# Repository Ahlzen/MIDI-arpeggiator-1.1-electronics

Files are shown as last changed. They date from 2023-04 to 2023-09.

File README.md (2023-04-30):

# MIDI-arpeggiator-1.1-electronics
Schematics and PCB design for MIDI Arpeggiator v1.1

For KiCad 7

Firmware at
https://github.com/Ahlzen/MIDI-arpeggiator-1.1-firmware

Case and panel at
https://github.com/Ahlzen/MIDI-arpeggiator-1.1-case

### 3rd Party Libraries used

Raspberry Pi Pico symbols, footprints and 3D models from
https://github.com/ncarandini/KiCad-RP-Pico
(CC-BY-SA 4.0)

Female DIN (MIDI) connector symbol and footprint from
https://github.com/nebs/eurocad

## Images and Resources

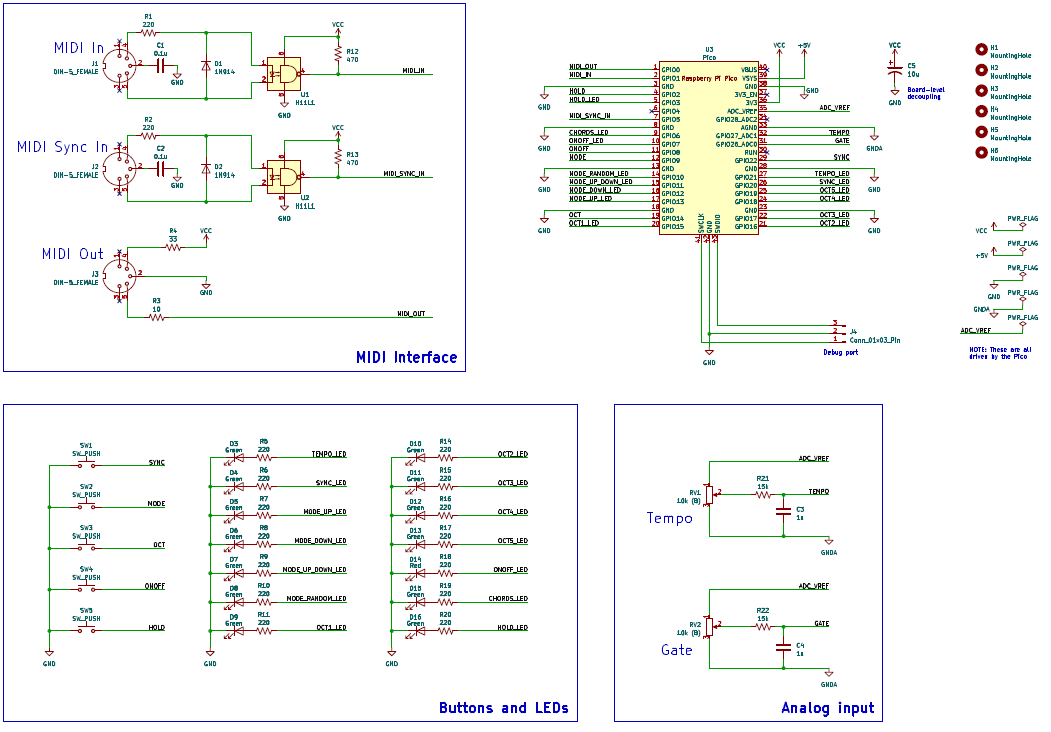
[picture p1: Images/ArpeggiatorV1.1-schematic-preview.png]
Schematic


[PDF Schematic](Images/ArpeggiatorV1.1.pdf)

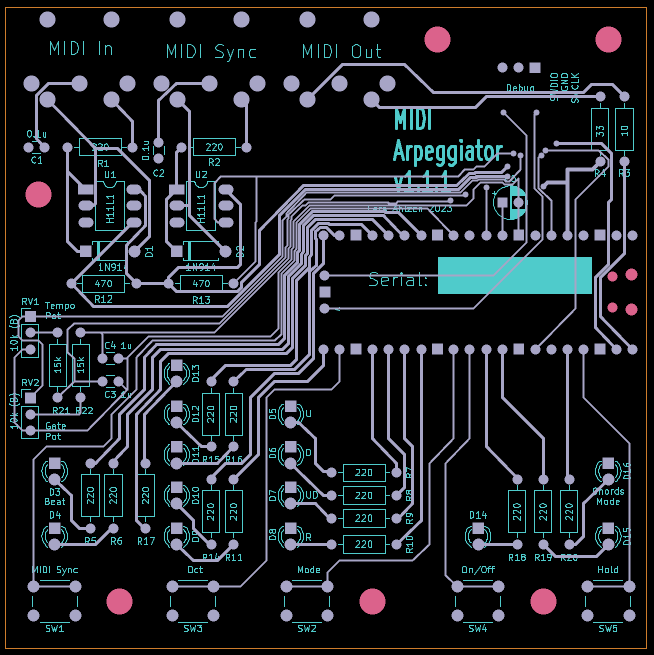
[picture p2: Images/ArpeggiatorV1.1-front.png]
PCB Front

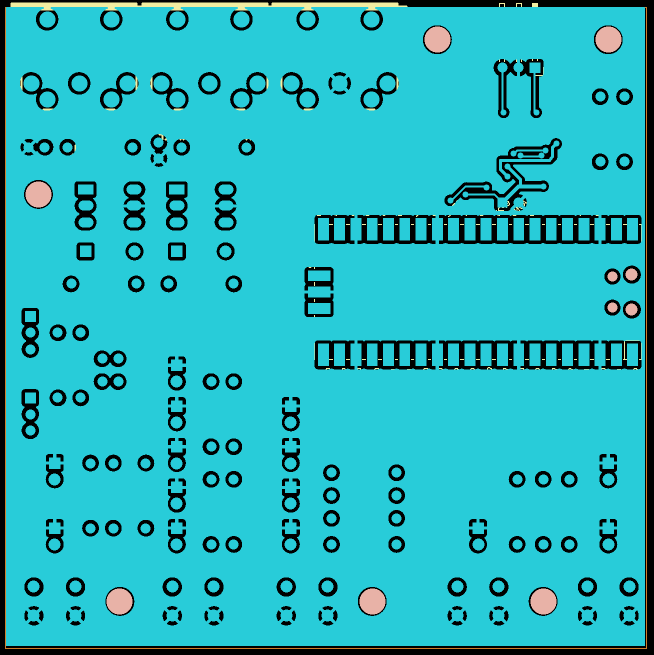
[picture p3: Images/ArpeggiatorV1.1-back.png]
PCB Back

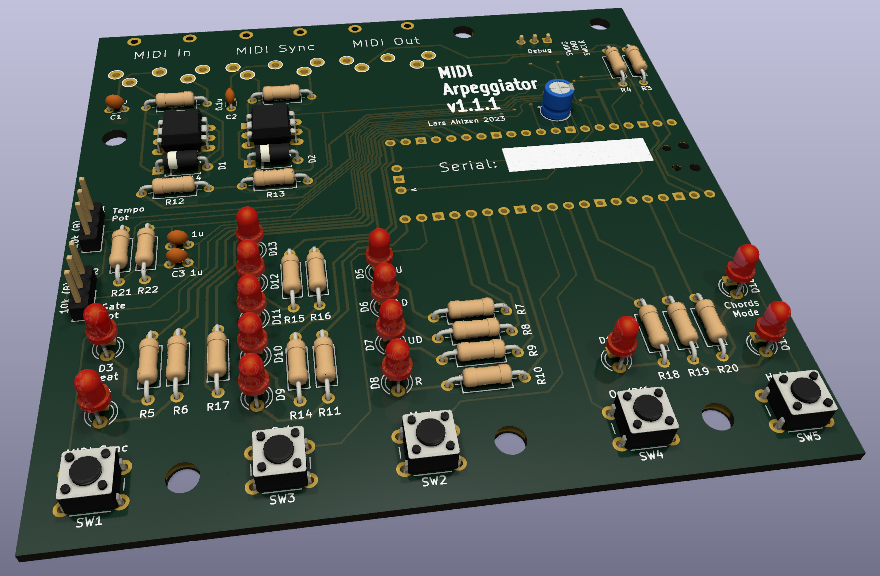
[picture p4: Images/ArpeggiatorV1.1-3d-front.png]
PCB Front (3D view)

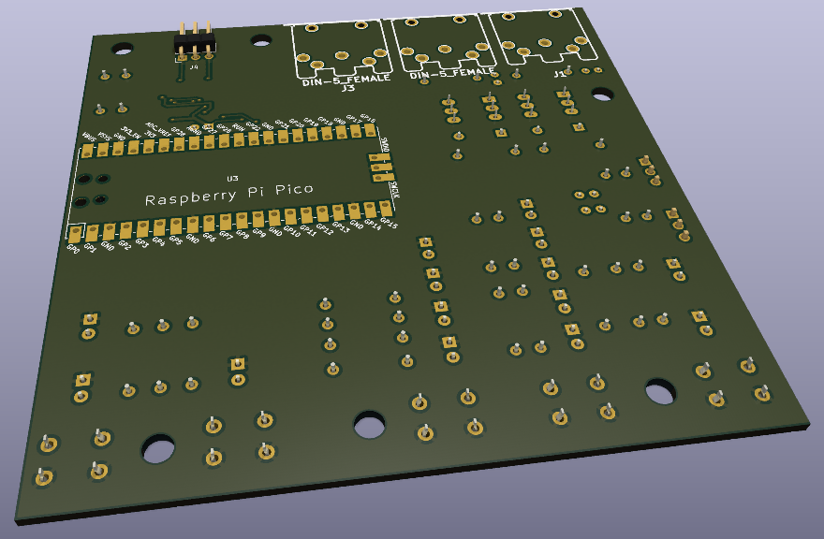
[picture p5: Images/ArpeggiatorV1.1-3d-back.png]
PCB Back (3D view)


## TODO

* Pull in KiCAD-RP-Pico and Eurocad libraries as submodules. [Done]
* Ensure all components values on schematic + PCB silkscreen [Done]
* Include proper BOM and build notes
* Add photos of assembled PCB

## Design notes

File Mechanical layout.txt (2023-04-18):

PCB Mechanical Layout
=====================
Notes on locations for panel elements (buttons, LEDs, connectors etc.)

All measurements in mm

Origin at top left
[0,0]->[100,0]
|
V
[0,100]

Buttons
-------
SW_SYNC   7.62, 92.71
SW_OCT   29.21, 92.71
SW_MODE  46.99, 92.71
SW_ONOFF 73.66, 92.71
SW_HOLD  93.98, 92.71

LEDs
----
Tempo:  7.62, 72.39
Sync:   7.62, 82.55
Oct1:   26.67, 82.55
Oct2:   26.67, 76.20
Oct3:   26.67, 69.85
Oct4:   26.67, 63.50
Oct5:   26.67, 57.15
ModeR:  44.45, 82.55
ModeUD: 44.45, 76.20
ModeD:  44.45, 69.85
ModeU:  44.45, 63.50
OnOff:  73.66, 82.55
Hold:   93.98, 82.55
Chords: 93.98, 72.39

Holes
-----
Top row:
5.08, 29.21
67.31, 5.08
93.98, 5.08
Bottom row:
17.78, 92.71
57.15, 92.71
83.82, 92.71

Back edge cutouts (below PCB)
----------------------------
MIDI ports: 0mm - 63mm  TODO: height
Debug port: 74mm - 86mm  TODO: height

Right edge cutouts (below PCB)
------------------------------
MicroUSB (power): 40mm - 49mm  TODO: height

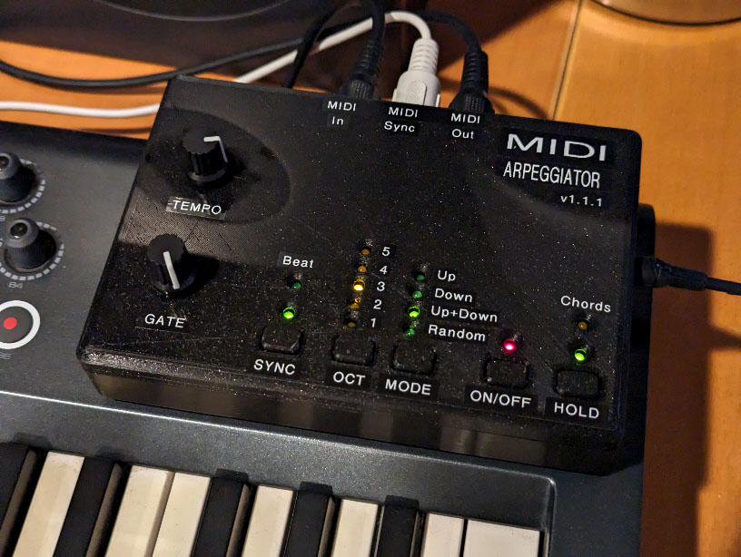
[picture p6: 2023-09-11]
Images/ArpeggiatorV1.1.1-photo.jpg

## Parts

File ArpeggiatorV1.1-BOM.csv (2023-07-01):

Reference | Value | Footprint | Qty
C1, C2 | 0.1u | Capacitor_THT:C_Disc_D3.0mm_W1.6mm_P2.50mm | 2
C3, C4 | 1u | Capacitor_THT:C_Disc_D3.0mm_W1.6mm_P2.50mm | 2
C5 | 10u | Capacitor_THT:CP_Radial_D5.0mm_P2.50mm | 1
D1, D2 | 1N914 | Diode_THT:D_A-405_P7.62mm_Horizontal | 2
D3-D13, D15, D16 | Green | LED_THT:LED_D3.0mm | 13
D14 | Red | LED_THT:LED_D3.0mm | 1
H1-H6 | MountingHole | MountingHole:MountingHole_4mm | 6
J1-J3 | DIN-5_FEMALE | Eurocad:MIDI_DIN5 | 3
J4 | Conn_01x03_Pin | Connector_PinHeader_2.54mm:PinHeader_1x03_P2.54mm_Horizontal | 1
R1, R2, R5-R11, R14-R20 | 220 | Resistor_THT:R_Axial_DIN0207_L6.3mm_D2.5mm_P10.16mm_Horizontal | 16
R3 | 10 | Resistor_THT:R_Axial_DIN0207_L6.3mm_D2.5mm_P10.16mm_Horizontal | 1
R4 | 33 | Resistor_THT:R_Axial_DIN0207_L6.3mm_D2.5mm_P10.16mm_Horizontal | 1
R12, R13 | 470 | Resistor_THT:R_Axial_DIN0207_L6.3mm_D2.5mm_P10.16mm_Horizontal | 2
R21, R22 | 15k | Resistor_THT:R_Axial_DIN0207_L6.3mm_D2.5mm_P10.16mm_Horizontal | 2
RV1, RV2 | 10k (B) | Connector_PinHeader_2.54mm:PinHeader_1x03_P2.54mm_Vertical | 2
SW1-SW5 | SW_PUSH | Button_Switch_THT:SW_PUSH_6mm | 5
U1, U2 | H11L1 | Package_DIP:DIP-6_W7.62mm_LongPads | 2
U3 | Pico | MCU_RaspberryPi_and_Boards:RPi_Pico_SMD_TH | 1

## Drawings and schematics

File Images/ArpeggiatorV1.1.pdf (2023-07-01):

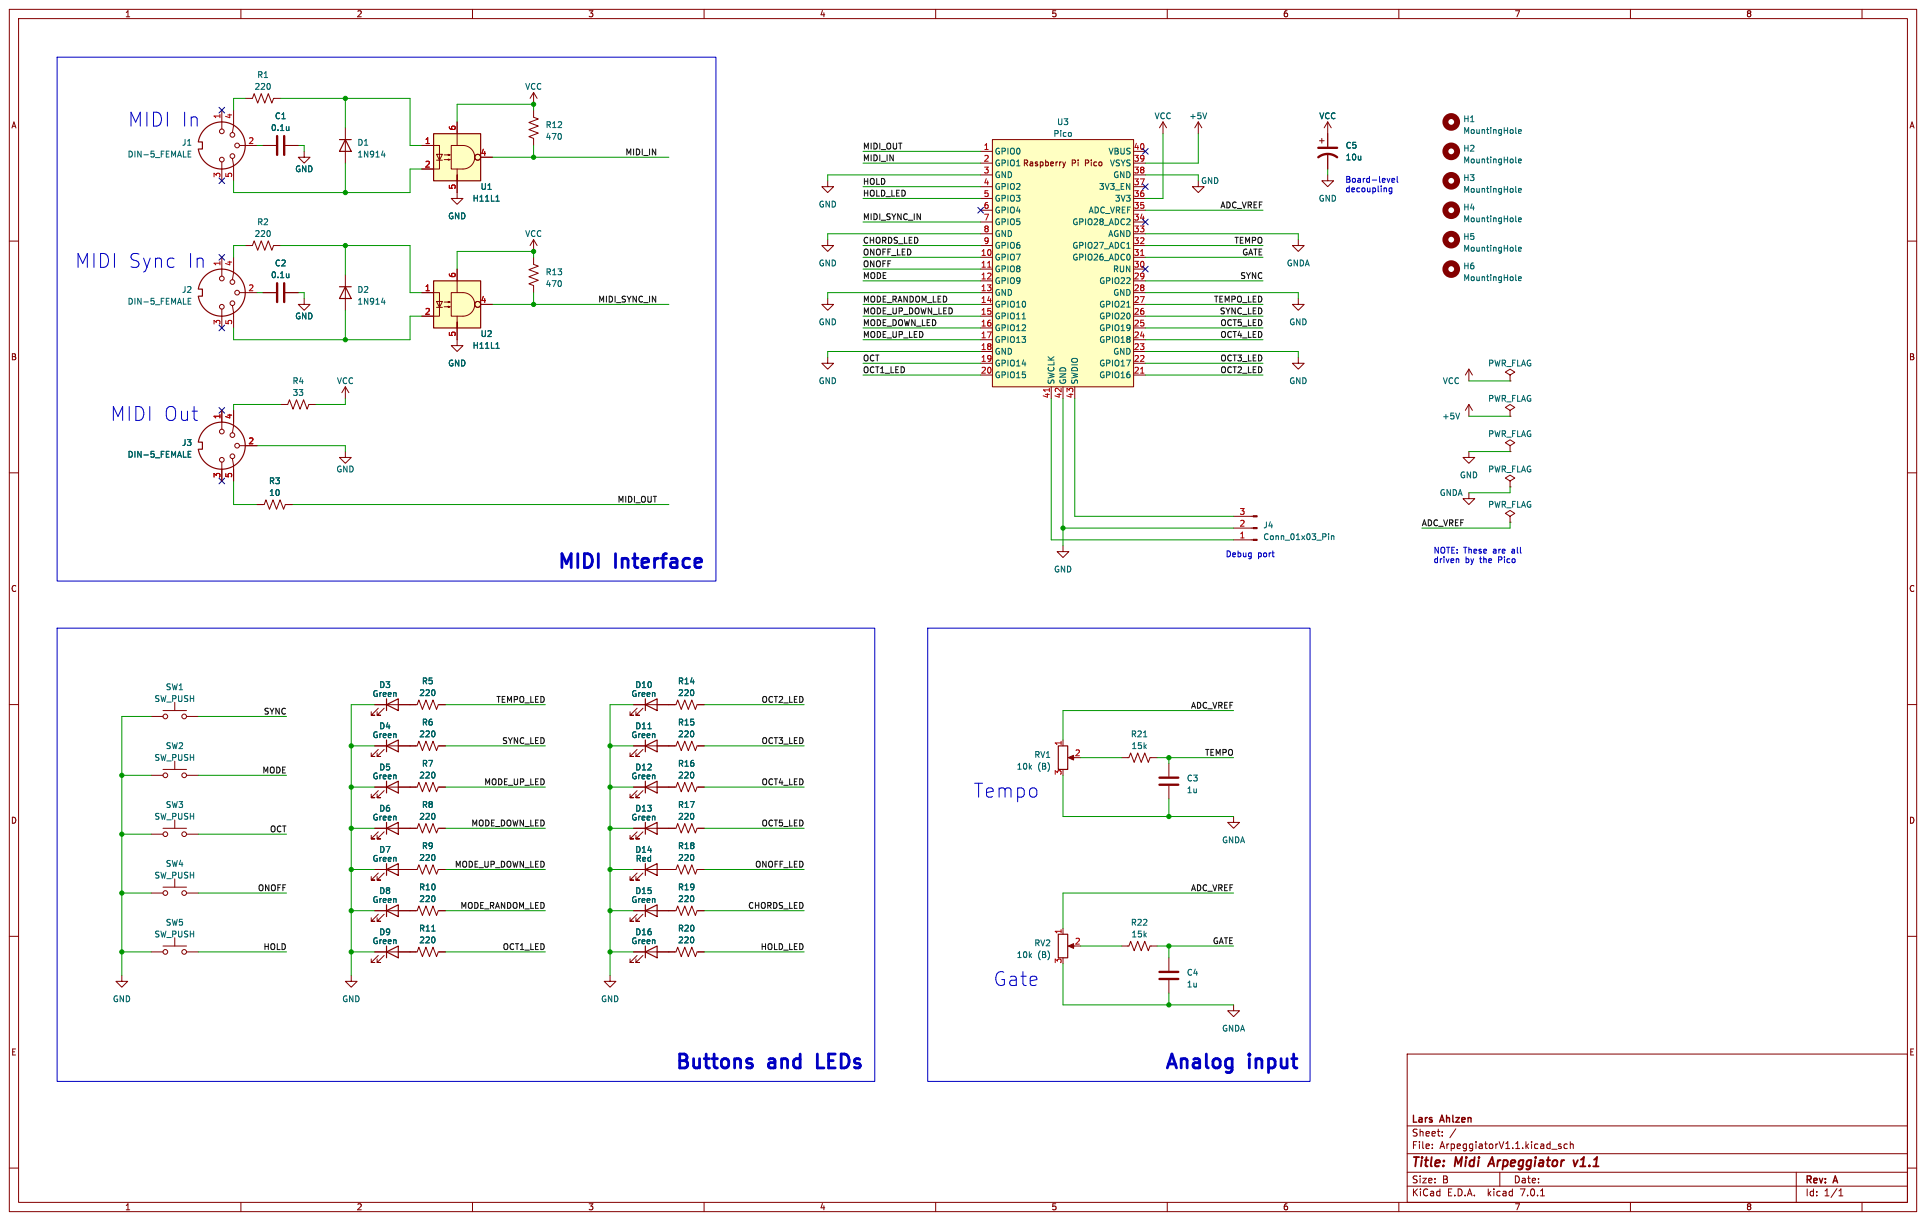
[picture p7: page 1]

H6 MountingHole H3 MountingHole H5 MountingHole H1 MountingHole H2 MountingHole H4 MountingHole VCC

MODE Buttons and LEDs

File: ArpeggiatorV1.1.kicad_sch Sheet: / Lars Ahlzen

Id: 1/1 Title: Midi Arpeggiator v1.1

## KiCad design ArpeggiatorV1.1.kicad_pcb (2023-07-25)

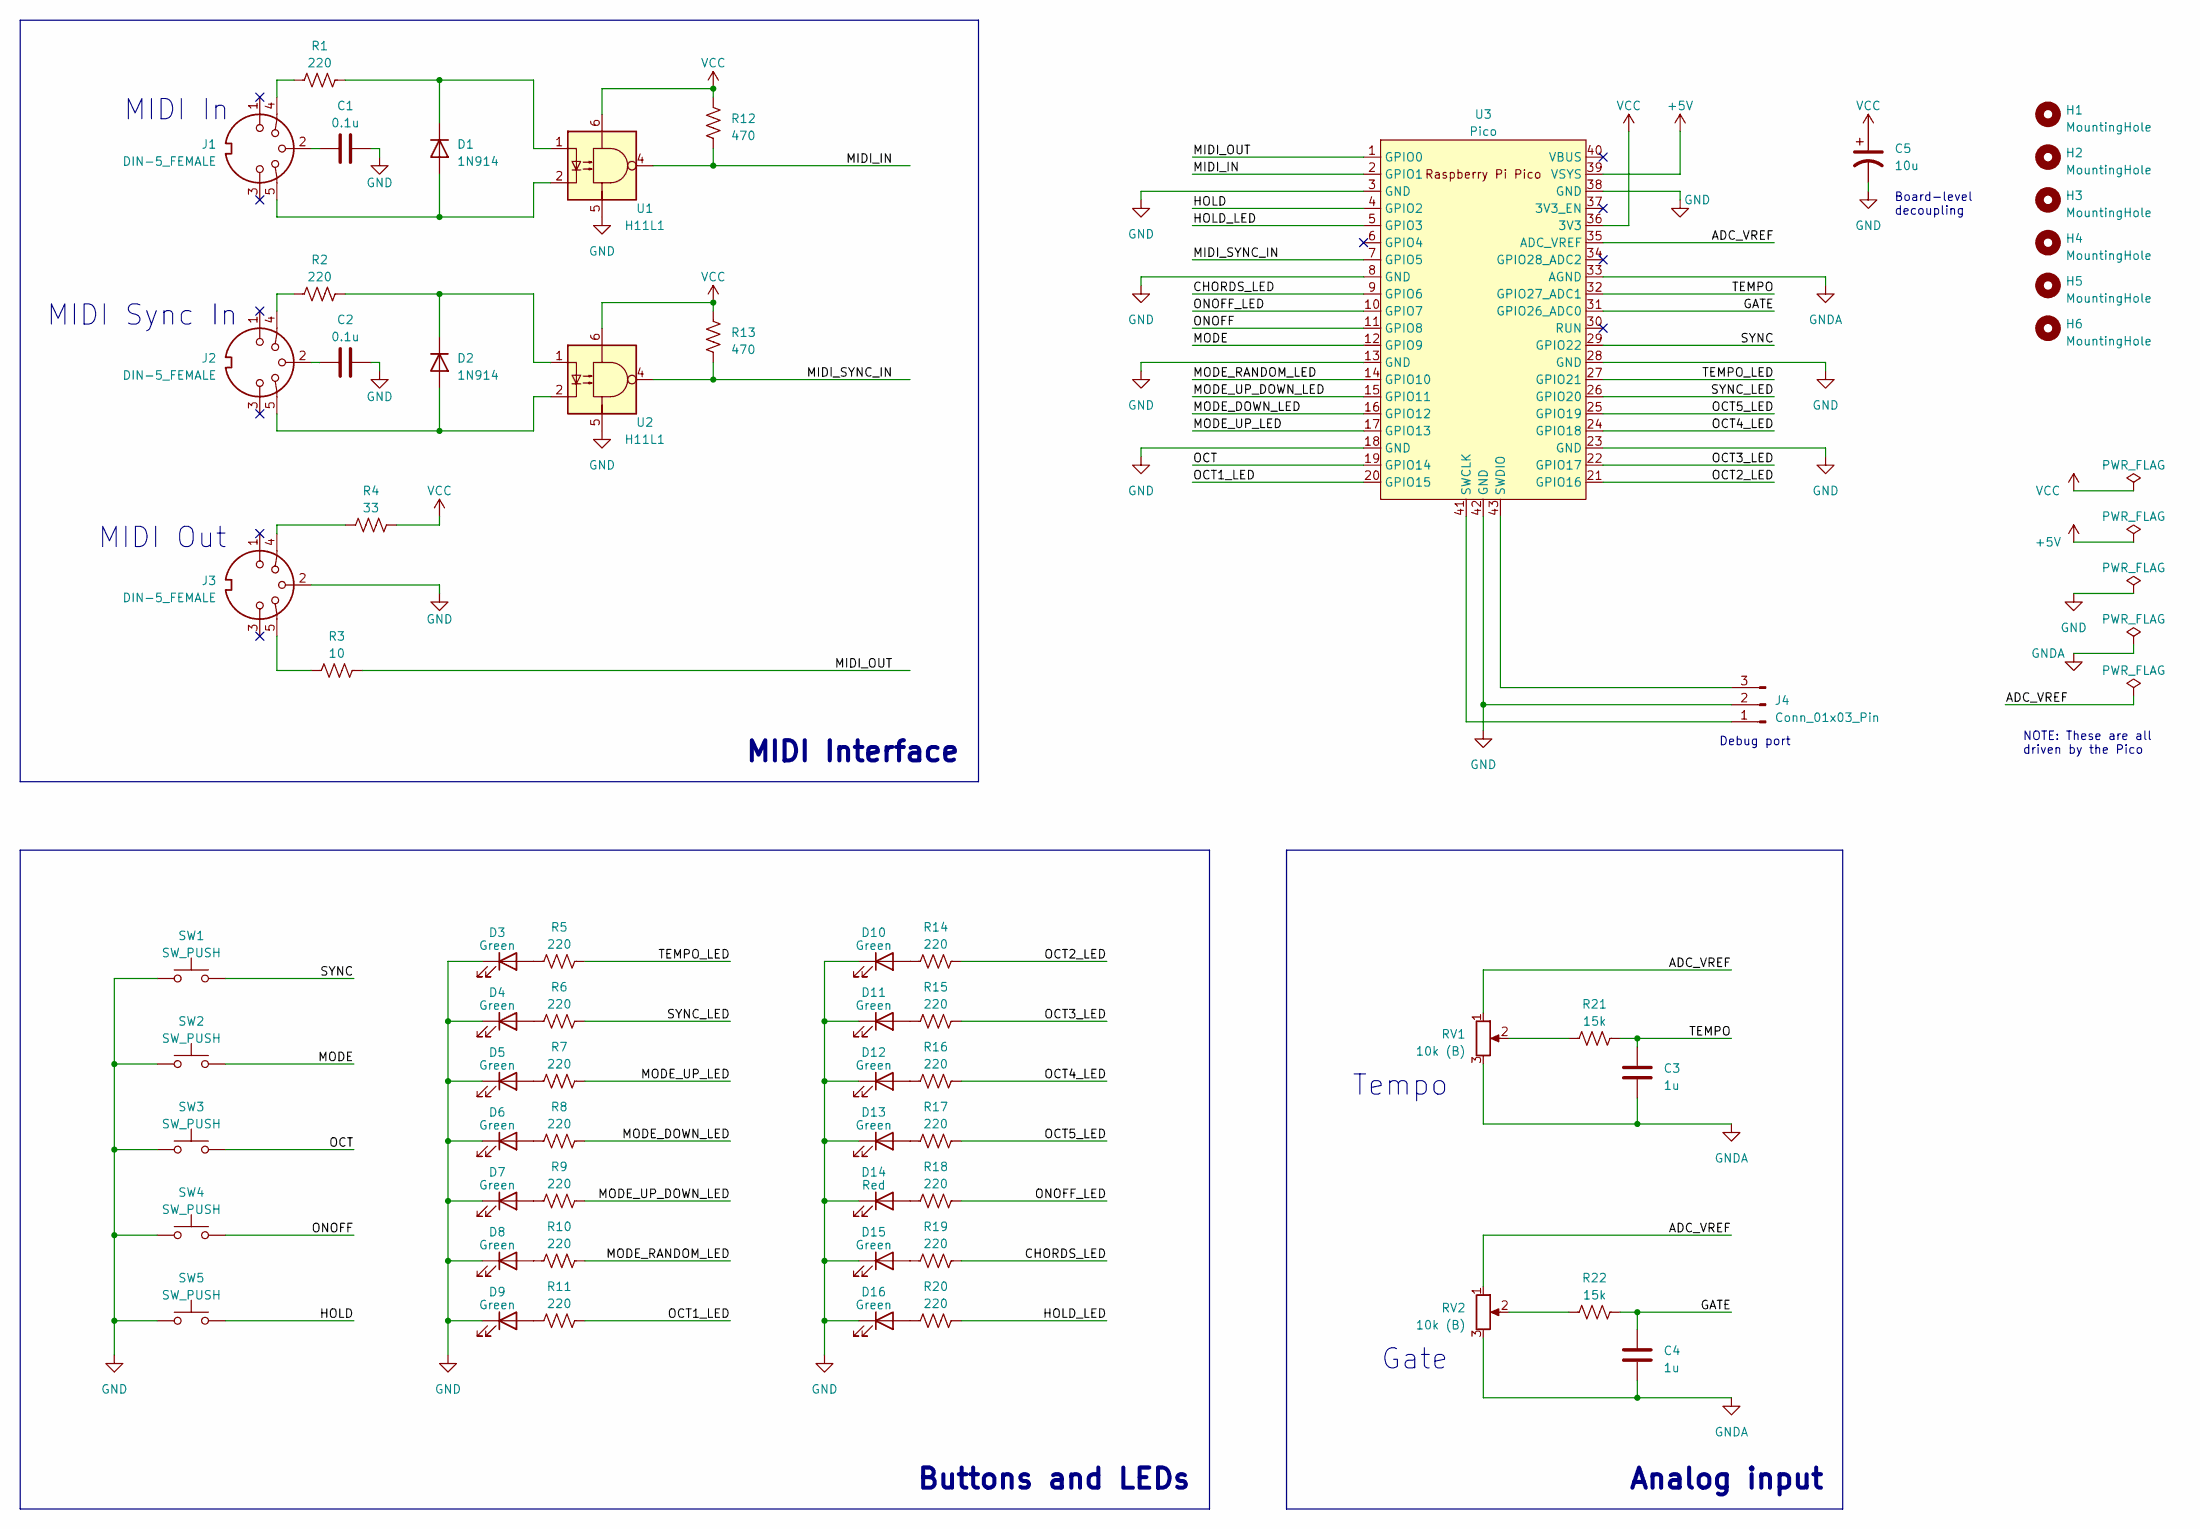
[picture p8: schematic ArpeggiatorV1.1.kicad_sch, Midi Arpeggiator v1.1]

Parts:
C1, C2: 0.1u; C_Disc_D3.0mm_W1.6mm_P2.50mm
C3, C4: 1u; C_Disc_D3.0mm_W1.6mm_P2.50mm
C5: 10u; CP_Radial_D5.0mm_P2.50mm
D1, D2: 1N914; D_A-405_P7.62mm_Horizontal
D3, D4, D5, D6, D7, D8, D9, D10, D11, D12, D13, D15, D16: Green; LED_D3.0mm
D14: Red; LED_D3.0mm
H1, H2, H3, H4, H5, H6: MountingHole; MountingHole_4mm
J1, J2, J3: DIN-5_FEMALE; MIDI_DIN5
J4: Conn_01x03_Pin; PinHeader_1x03_P2.54mm_Horizontal
R1, R2, R5, R6, R7, R8, R9, R10, R11, R14, R15, R16, R17, R18, R19, R20: 220; R_Axial_DIN0207_L6.3mm_D2.5mm_P10.16mm_Horizontal
R3: 10; R_Axial_DIN0207_L6.3mm_D2.5mm_P10.16mm_Horizontal
R4: 33; R_Axial_DIN0207_L6.3mm_D2.5mm_P10.16mm_Horizontal
R12, R13: 470; R_Axial_DIN0207_L6.3mm_D2.5mm_P10.16mm_Horizontal
R21, R22: 15k; R_Axial_DIN0207_L6.3mm_D2.5mm_P10.16mm_Horizontal
RV1, RV2: 10k (B); PinHeader_1x03_P2.54mm_Vertical
SW1, SW2, SW3, SW4, SW5: SW_PUSH; SW_PUSH_6mm
U1, U2: H11L1; DIP-6_W7.62mm_LongPads
U3: Pico; RPi_Pico_SMD_TH

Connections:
+5V: U3.39 (VSYS)
/ADC_VREF: RV1.1, RV2.1, U3.35 (ADC_VREF)
/CHORDS_LED: R19.2, U3.9 (GPIO6)
/GATE: C4.1, R22.2, U3.31 (GPIO26_ADC0)
/HOLD: SW5.2, U3.4 (GPIO2)
/HOLD_LED: R20.2, U3.5 (GPIO3)
/MIDI_IN: R12.2, U1.4, U3.2 (GPIO1)
/MIDI_OUT: R3.2, U3.1 (GPIO0)
/MIDI_SYNC_IN: R13.2, U2.4, U3.7 (GPIO5)
/MODE: SW2.2, U3.12 (GPIO9)
/MODE_DOWN_LED: R8.2, U3.16 (GPIO12)
/MODE_RANDOM_LED: R10.2, U3.14 (GPIO10)
/MODE_UP_DOWN_LED: R9.2, U3.15 (GPIO11)
/MODE_UP_LED: R7.2, U3.17 (GPIO13)
/OCT: SW3.2, U3.19 (GPIO14)
/OCT1_LED: R11.2, U3.20 (GPIO15)
/OCT2_LED: R14.2, U3.21 (GPIO16)
/OCT3_LED: R15.2, U3.22 (GPIO17)
/OCT4_LED: R16.2, U3.24 (GPIO18)
/OCT5_LED: R17.2, U3.25 (GPIO19)
/ONOFF: SW4.2, U3.11 (GPIO8)
/ONOFF_LED: R18.2, U3.10 (GPIO7)
/SYNC: SW1.2, U3.29 (GPIO22)
/SYNC_LED: R6.2, U3.26 (GPIO20)
/TEMPO: C3.1, R21.2, U3.32 (GPIO27_ADC1)
/TEMPO_LED: R5.2, U3.27 (GPIO21)
GND: C1.2, C2.2, C5.2, D3.1 (K), D4.1 (K), D5.1 (K), D6.1 (K), D7.1 (K), D8.1 (K), D9.1 (K), D10.1 (K), D11.1 (K), D12.1 (K), D13.1 (K), D14.1 (K), D15.1 (K), D16.1 (K), J3.2, J4.2, SW1.1, SW2.1, SW3.1, SW4.1, SW5.1, U1.5, U2.5, U3.3 (GND), U3.8 (GND), U3.13 (GND), U3.18 (GND), U3.23 (GND), U3.28 (GND), U3.38 (GND), U3.42 (GND)
GNDA: C3.2, C4.2, RV1.3, RV2.3, U3.33 (AGND)
unnamed: C1.1, J1.2
unnamed: C2.1, J2.2
unnamed: D1.2 (A), J1.5, U1.2
unnamed: D1.1 (K), R1.2, U1.1
unnamed: D2.2 (A), J2.5, U2.2
unnamed: D2.1 (K), R2.2, U2.1
unnamed: D3.2 (A), R5.1
unnamed: D4.2 (A), R6.1
unnamed: D5.2 (A), R7.1
unnamed: D6.2 (A), R8.1
unnamed: D7.2 (A), R9.1
unnamed: D8.2 (A), R10.1
unnamed: D9.2 (A), R11.1
unnamed: D10.2 (A), R14.1
unnamed: D11.2 (A), R15.1
unnamed: D12.2 (A), R16.1
unnamed: D13.2 (A), R17.1
unnamed: D14.2 (A), R18.1
unnamed: D15.2 (A), R19.1
unnamed: D16.2 (A), R20.1
unnamed: J1.4, R1.1
unnamed: J2.4, R2.1
unnamed: J3.4, R4.1
unnamed: J3.5, R3.1
unnamed: J4.1, U3.41 (SWCLK)
unnamed: J4.3, U3.43 (SWDIO)
unnamed: R21.1, RV1.2
unnamed: R22.1, RV2.2
VCC: C5.1, R4.2, R12.1, R13.1, U1.6, U2.6, U3.36 (3V3)

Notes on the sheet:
Gate
Board-level decoupling
Buttons and LEDs
MIDI In
MIDI Out
NOTE: These are all driven by the Pico
Tempo
Analog input
MIDI Interface
MIDI Sync In
Debug port

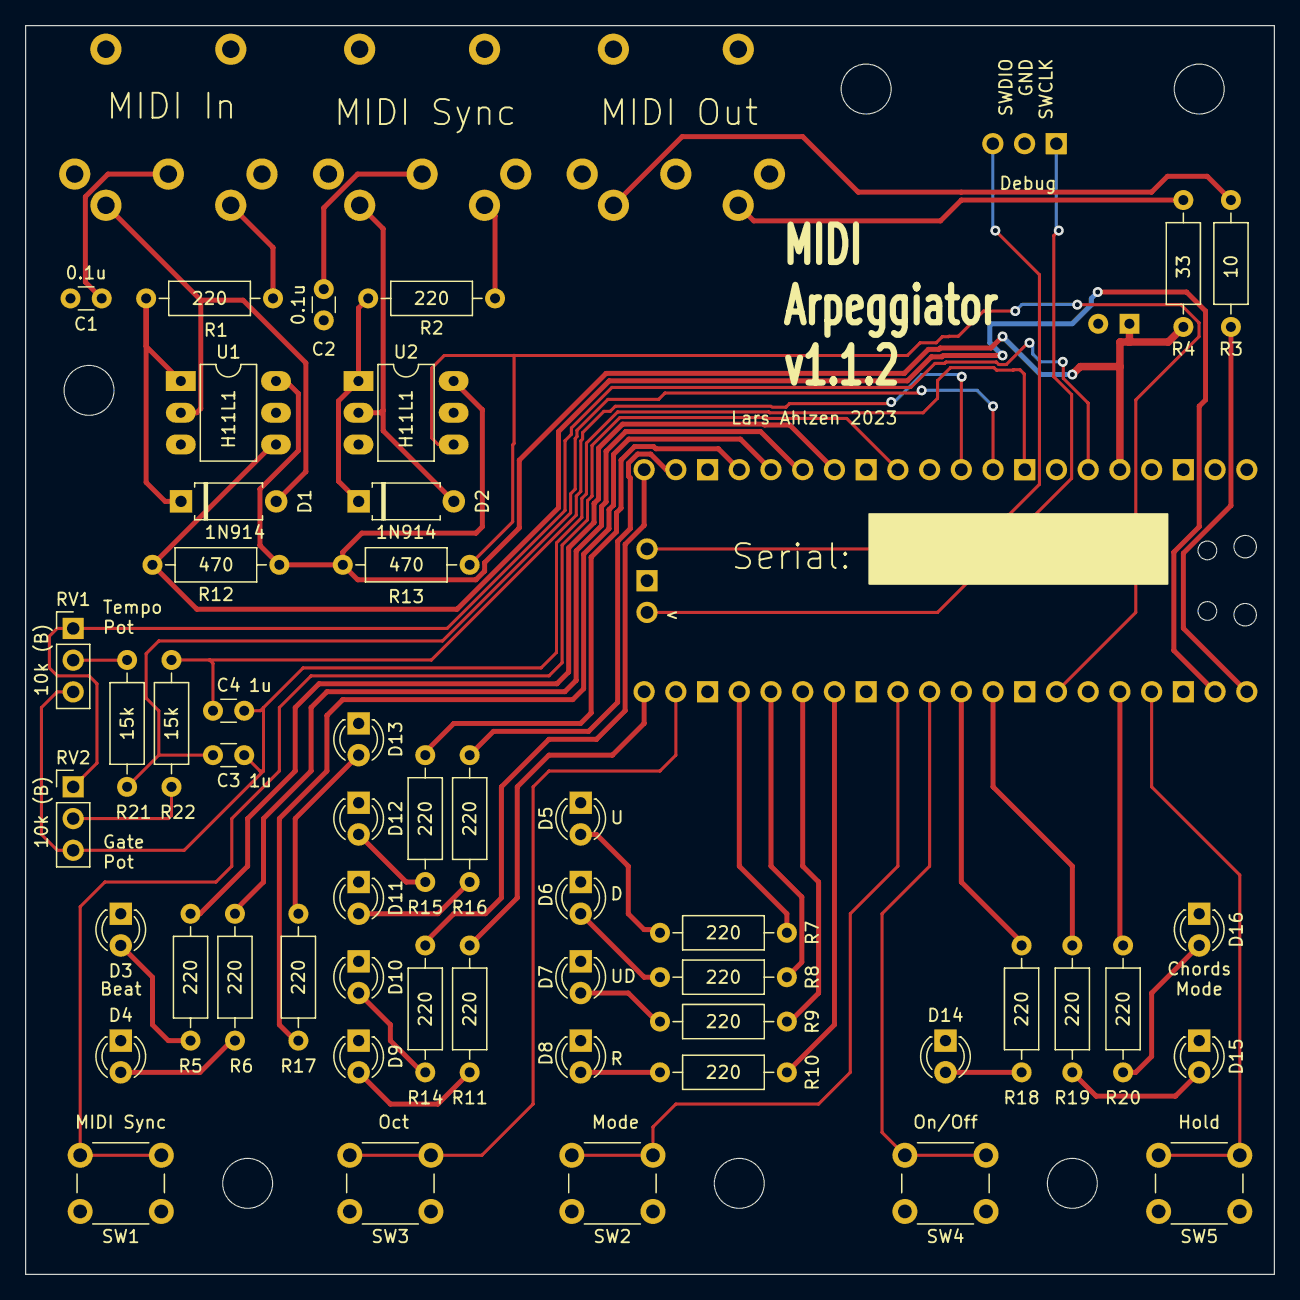
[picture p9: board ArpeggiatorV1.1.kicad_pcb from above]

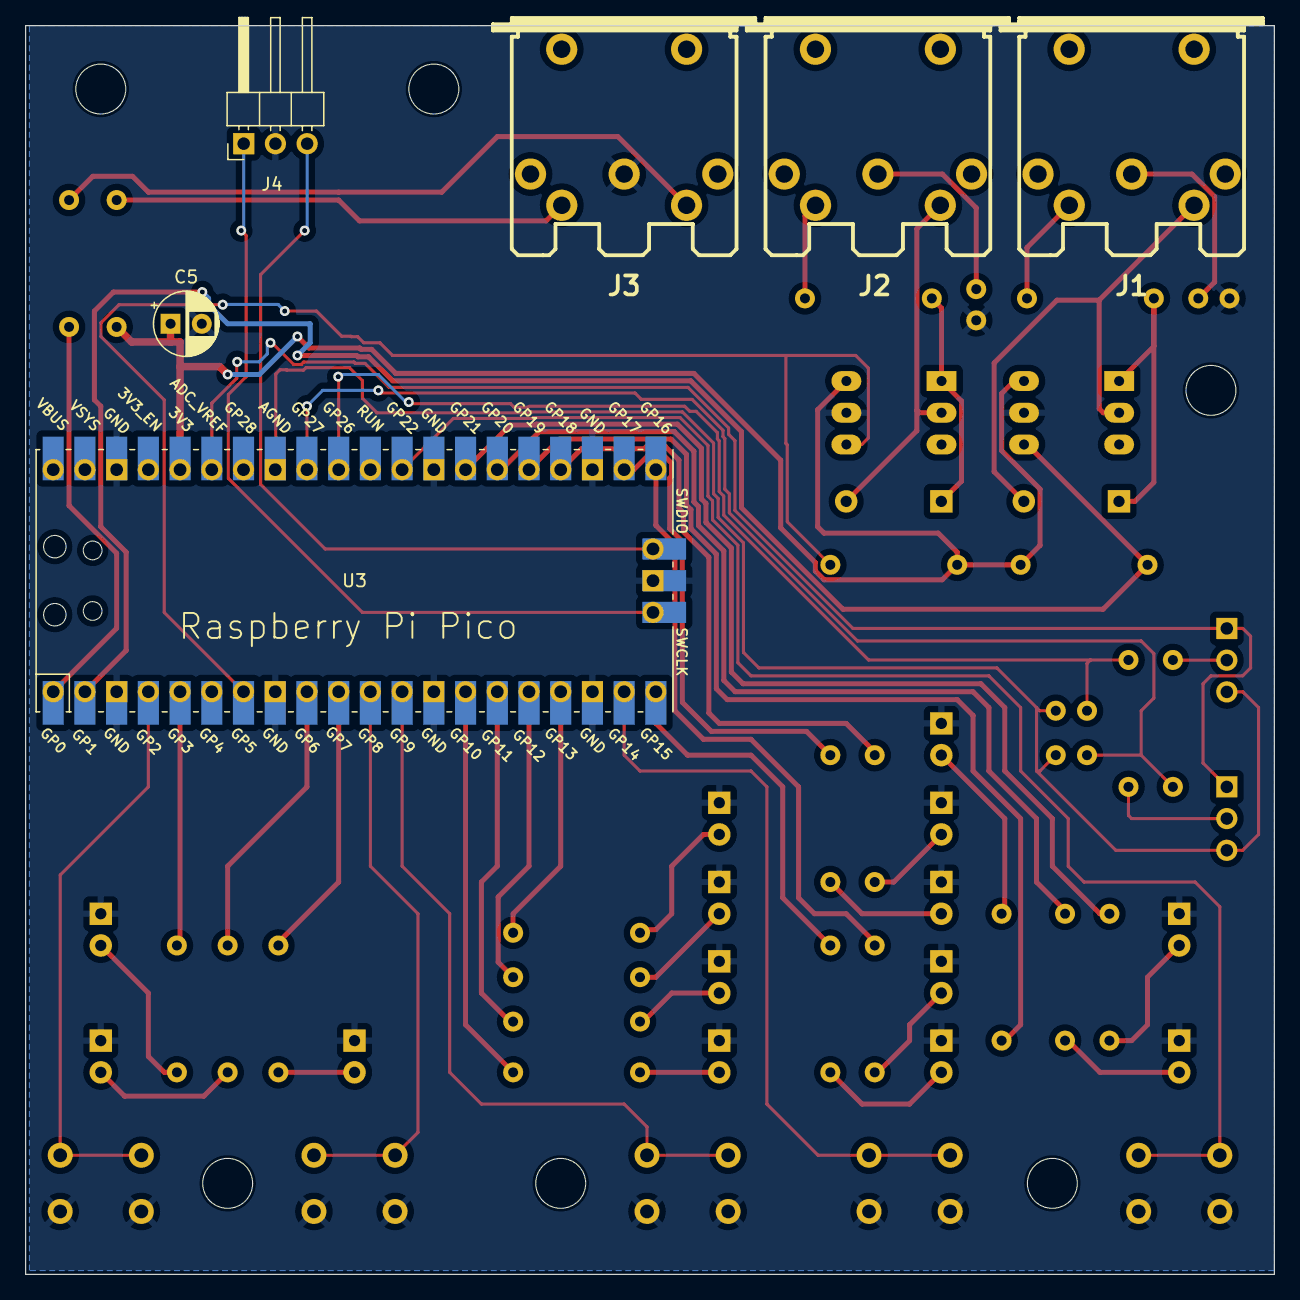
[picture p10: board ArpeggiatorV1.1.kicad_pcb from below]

Board: 2 copper layers, 100.0 x 100.0 mm, 63 parts (6 on the bottom side), 56 nets.

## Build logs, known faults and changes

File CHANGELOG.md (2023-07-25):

# Arpeggiator 1.1 - Hardware changelog

## v1.1.2

* Fixed PCB routing error for TEMPO net.
* Cleaned up some PCB labels on silkscreen.

## v1.1.1

* Changed MIDI interface to use H11L1 optocouplers running on
  3v3 only, resulting in simpler BOM and more stable operation.
* Included Bill-of-Materials (.csv format)
* Added silkscreen notes for debug pins, LEDs and MIDI ports
  (for easier operation/testing without case)

## v1.1.0

* Initial hardware version.

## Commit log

2023-04-07 Initial schematic.
    [ArpeggiatorV1.1.kicad_pcb, ArpeggiatorV1.1.kicad_sch]
2023-04-07 Cleaned up schematic
    [ArpeggiatorV1.1.kicad_sch]
2023-04-07 Added "Eurocad" KiCAD symbol/footprint library
2023-04-07 Updated component footprints. Set initial PCB design rules for common prototyping houses like PCBWay and OSHPark.
    [ArpeggiatorV1.1.kicad_pcb, ArpeggiatorV1.1.kicad_sch]
2023-04-14 Adjusted pin assigments for a cleaner layout. Partially laid out and routed board.
    [ArpeggiatorV1.1.kicad_pcb, ArpeggiatorV1.1.kicad_sch]
2023-04-14 Mostly finished PCB layout.
    [ArpeggiatorV1.1.kicad_pcb, ArpeggiatorV1.1.kicad_sch]
2023-04-14 Finished routing missing signals.
    [ArpeggiatorV1.1.kicad_pcb]
2023-04-14 Cleaned up PCB and fixed some DRC warnings.
    [ArpeggiatorV1.1.kicad_pcb]
2023-04-14 Fixed minor PCB issues.
    [ArpeggiatorV1.1.kicad_pcb]
2023-04-14 More minor PCB adjustments.
    [ArpeggiatorV1.1.kicad_pcb]
2023-04-14 Added gerbers + drill files.
    [ArpeggiatorV1.1-B_Cu.gbl, ArpeggiatorV1.1-B_Mask.gbs, ArpeggiatorV1.1-B_Paste.gbp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]
2023-04-14 Cleaned up labels on schematic.
    [ArpeggiatorV1.1.kicad_sch]
2023-04-15 Added PCB and schematic images for readme.
2023-04-15 Added notes about mechanical layout (locations of panel/case elements)
2023-04-15 Minor PCB corrections and cleanups.
    [ArpeggiatorV1.1.kicad_pcb]
2023-04-29 Added component values to PCB silkscreen.
    [ArpeggiatorV1.1.kicad_pcb, ArpeggiatorV1.1.kicad_sch]
2023-04-30 Added 3rd party kicad libraries as submodules.
2023-07-01 Updated schematic+PCB with new MIDI interface section.
    [ArpeggiatorV1.1.kicad_pcb, ArpeggiatorV1.1.kicad_sch]
2023-07-01 Updated gerbers, images and changelog.
    [ArpeggiatorV1.1-B_Cu.gbl, ArpeggiatorV1.1-B_Mask.gbs, ArpeggiatorV1.1-B_Paste.gbp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]
2023-07-01 Included bill-of-materials.
2023-07-01 Added actual BOM file.
    [ArpeggiatorV1.1-BOM.csv]
2023-07-01 Updated schematic thumbnail image.
2023-07-25 Fixed PCB routing error for TEMPO net. Cleaned up some PCB labels on silkscreen.
    [ArpeggiatorV1.1.kicad_pcb]
2023-09-11 Added photo of case.
